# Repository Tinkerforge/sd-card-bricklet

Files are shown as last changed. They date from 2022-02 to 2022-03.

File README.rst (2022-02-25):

SD Card Bricklet
================

**This Bricklet is currently in development.**

This repository contains the firmware source code and the hardware design
files. The documentation generator configs can be found at
https://github.com/Tinkerforge/generators

Repository Content
------------------

software/:
 * examples/: Examples for all supported languages
 * build/: Compiled files
 * src/: Source code of firmware
 * Makefile: Makefile to build project

hardware/:
 * Contains KiCad project files and additionally schematics as PDF

datasheets/:
 * Contains datasheets for sensors and complex ICs that are used

Hardware
--------

The hardware is designed with the open source EDA Suite KiCad
(http://www.kicad.org). Before you are able to open the files,
you have to install the Tinkerforge kicad-libraries
(https://github.com/Tinkerforge/kicad-libraries). You can either clone
them directly in hardware/ or clone them in a separate folder and
symlink them into hardware/
(ln -s kicad_path/kicad-libraries project_path/hardware). After that you
can open the .pro file in hardware/ with KiCad and from there view and
modify the schematics and the PCB layout.

Software
--------

If you want to do your own Brick/Bricklet firmware development we highly
recommend that you use our build environment setup script and read the
tutorial (https://www.tinkerforge.com/en/doc/Tutorials/Tutorial_Build_Environment/Tutorial.html).

To compile the C code we recommend you to install the newest GNU Arm Embedded
Toolchain (https://launchpad.net/gcc-arm-embedded/+download).
You also need to install bricklib2 (https://github.com/Tinkerforge/bricklib2).

You can either clone it directly in software/src/ or clone it in a
separate folder and symlink it into software/src/
(ln -s bricklib_path/bricklib2 project_path/software/src/). Finally make sure to
have CMake installed (http://www.cmake.org/cmake/resources/software.html).

After that you can build the firmware by invoking make in software/.
The firmware (.zbin) can then be found in software/build/ and uploaded
with brickv (click button "Flashing" on start screen).

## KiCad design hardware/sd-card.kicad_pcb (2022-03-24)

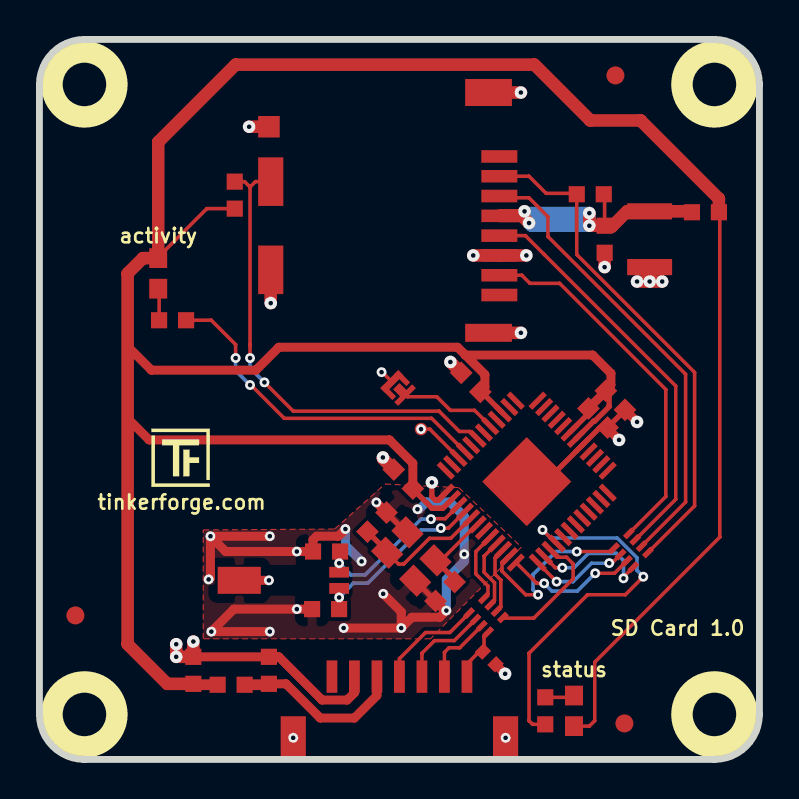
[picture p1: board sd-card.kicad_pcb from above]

Board: 2 copper layers, 40.0 x 40.0 mm, 39 parts (0 on the bottom side), 31 nets.

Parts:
C1: 220pF; C0402F
C2, C5: 1uF; C0603F
C3, C4: 10pF; C0603F
C6, C7, C8, C11: 100nF; C0603F
C9: 220nF; C0603F
C10: 100uF; C1210
C12, C13: 15pF; C0603F
D1: blue; D0603E
D2: red; D0603E
FB1: FILTER; R0603F
Fiducial_Mark: VAL**; Fiducial_Mark
Fiducial_Mark#2, Fiducial_Mark#3: VAL**; Fiducial_Mark
J1: DM3CS; SD-Card-DM3CS
L1: FB; R0603F
P1: CON-SENSOR2
P2: BOOT; SolderJumper
P3: Debug; DEBUG_PAD
R1, R2: 10k; R0603F
R3, R4: 1k; R0603F
RP1, RP2: 82; 4X0402
U1: XMC1404; QFN48-EP2
U2, U3, U4, U5: DRILL; DRILL_NP
VAL: WEEE_7mm
VAL#2: CE_5mm
X1: 16MHz; CRYSTAL_3225
X2: 32.768kHz; AB26TRQ

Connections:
GND: C1.2, C2.1, C3.2, C4.2, C5.1, C6.2, C7.2, C8.2, C9.2, C10.2, C11.2, C12.1, C13.1, J1.6, J1.S, P1.2, P1.EP, P2.1, U1.17, U1.37, U1.EP, X1.3, X2.3
unnamed: C1.1, P1.7, RP1.4
unnamed: C2.2, FB1.1, P1.3
unnamed: C3.1, U1.41, X1.2
unnamed: C4.1, U1.42, X1.1
unnamed: C10.1, C11.1, J1.4, L1.1, R2.2
unnamed: D1.2, R4.1
unnamed: D2.2, R3.1
unnamed: J1.2, R2.1, RP2.1
unnamed: J1.3, RP2.2
unnamed: J1.5, RP2.3
unnamed: J1.7, RP2.4
unnamed: P1.4, RP1.1
unnamed: P1.5, RP1.2
unnamed: P1.6, RP1.3
unnamed: P2.2, U1.29
unnamed: P3.1, U1.34
unnamed: R3.2, U1.33
unnamed: R4.2, U1.4
RTC-XTAL1: C13.2, U1.39, X2.2
RTC-XTAL2: C12.2, U1.40, X2.1
S-CLK: RP1.7, U1.45
S-CS: RP1.8, U1.44
S-MISO: RP1.5, U1.3
S-MOSI: RP1.6, U1.46
SD-CDS: J1.CDS, R1.1, U1.31
SD-CLK: RP2.6, U1.1
SD-CS: RP2.8, U1.2
SD-MISO: RP2.5, U1.47
SD-MOSI: RP2.7, U1.48
VCC: C5.2, C6.1, C7.1, C8.1, C9.1, D1.1, D2.1, FB1.2, L1.2, R1.2, U1.18, U1.19, U1.27, U1.38

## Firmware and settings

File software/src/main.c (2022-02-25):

/* sd-card-bricklet
 * Copyright (C) 2022 Olaf Lüke <olaf@tinkerforge.com>
 *
 * main.c: Initialization for SD Card Bricklet
 *
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
 * You should have received a copy of the GNU Lesser General Public
 * License along with this library; if not, write to the
 * Free Software Foundation, Inc., 59 Temple Place - Suite 330,
 * Boston, MA 02111-1307, USA.
 */

#include <stdio.h>
#include <stdbool.h>

#include "configs/config.h"

#include "bricklib2/bootloader/bootloader.h"
#include "bricklib2/hal/system_timer/system_timer.h"
#include "bricklib2/logging/logging.h"
#include "communication.h"

int main(void) {
	logging_init();
	logd("Start SD Card Bricklet\n\r");

	communication_init();

	while(true) {
		bootloader_tick();
		communication_tick();
	}
}

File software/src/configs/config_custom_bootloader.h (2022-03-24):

/* sd-card-bricklet
 * Copyright (C) 2022 Olaf Lüke <olaf@tinkerforge.com>
 *
 * config_custom_bootloader.h: Bootloader configurations for
 *                             SD Card Bricklet
 *
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
 * You should have received a copy of the GNU Lesser General Public
 * License along with this library; if not, write to the
 * Free Software Foundation, Inc., 59 Temple Place - Suite 330,
 * Boston, MA 02111-1307, USA.
 */

#ifndef CONFIG_CUSTOM_BOOTLOADER_H
#define CONFIG_CUSTOM_BOOTLOADER_H

#include "xmc_gpio.h"

// --- Basic defines ---
#define BOOTLOADER_DEVICE_IDENTIFIER   2172
#define BOOTLOADER_HW_VERSION_MAJOR    1
#define BOOTLOADER_HW_VERSION_MINOR    0
#define BOOTLOADER_HW_VERSION_REVISION 0

#define BOOTLOADER_STATUS_LED_PIN      P4_5
#define BOOTLOADER_BOOT_PAD_PIN        P4_6

#define BOOTLOADER_FLASH_EEPROM_SIZE   (4*256)
#define BOOTLOADER_FLASH_SIZE          (64*1024 - BOOTLOADER_FLASH_EEPROM_SIZE)

#define BOOTLOADER_FIX_POINTER_END

// --- Oscillator defines ---
#define OSCHP_FREQUENCY 16000000
#define DCLK_CLOCK_SRC  1
#define DCO1_CAL_SRC    1

// --- SPITFP ---
#define SPITFP_USIC_CHANNEL         USIC0_CH1
#define SPITFP_USIC                 XMC_SPI0_CH1

#define SPITFP_SCLK_PIN             P1_3
#define SPITFP_SCLK_INPUT           XMC_USIC_CH_INPUT_DX1
#define SPITFP_SCLK_SOURCE          0b000 // DX1A

#define SPITFP_SELECT_PIN           P1_1
#define SPITFP_SELECT_INPUT         XMC_USIC_CH_INPUT_DX2
#define SPITFP_SELECT_SOURCE        0b100 // DX2E

#define SPITFP_MOSI_PIN             P1_2
#define SPITFP_MOSI_INPUT           XMC_USIC_CH_INPUT_DX0
#define SPITFP_MOSI_SOURCE          0b001 // DX0B

#define SPITFP_MISO_PIN             P1_6
#define SPITFP_MISO_PIN_AF          (XMC_GPIO_MODE_OUTPUT_PUSH_PULL_ALT2 | P1_6_AF_U0C1_DOUT0)

#define SPITFP_RECEIVE_BUFFER_SIZE  1024
#define SPITFP_RECEIVE_BUFFER_MASK  (SPITFP_RECEIVE_BUFFER_SIZE-1) // If size is power of 2

#define SPITFP_SERVICE_REQUEST_RX   0
#define SPITFP_SERVICE_REQUEST_TX   1

#define SPITFP_IRQ_RX               9
#define SPITFP_IRQ_RX_PRIORITY      2
#define SPITFP_IRQ_TX               10
#define SPITFP_IRQ_TX_PRIORITY      3

#define SPITFP_TX_DATA_POINTER      16
#define SPITFP_TX_SIZE              XMC_USIC_CH_FIFO_SIZE_16WORDS
#define SPITFP_TX_LIMIT             8

#define SPITFP_RX_DATA_POINTER      0
#define SPITFP_RX_SIZE              XMC_USIC_CH_FIFO_SIZE_16WORDS
#define SPITFP_RX_LIMIT             0

// --- BOOTLOADER FUNCTIONS ---

// define bootloader functions to put them into the BootloaderFunctions struct
// These functions are in the bootloader code and can be used from the firmware

#define BOOTLOADER_FUNCTION_SPITFP_TICK
#define BOOTLOADER_FUNCTION_SEND_ACK_AND_MESSAGE
#define BOOTLOADER_FUNCTION_SPITFP_IS_SEND_POSSIBLE
#define BOOTLOADER_FUNCTION_AEABI_IDIV
#define BOOTLOADER_FUNCTION_AEABI_UIDIV
#define BOOTLOADER_FUNCTION_AEABI_IDIVMOD
#define BOOTLOADER_FUNCTION_AEABI_UIDIVMOD
#define BOOTLOADER_FUNCTION_GET_UID
#define BOOTLOADER_FUNCTION_READ_EEPROM_PAGE
#define BOOTLOADER_FUNCTION_WRITE_EEPROM_PAGE

#endif

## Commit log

2022-02-25 Add initial auto-generated firmware stub for SD Card Bricklet
    [cmake_config_custom.txt]
2022-03-24 add sd card bricklet 1.0
    [sd-card.kicad_pcb, sd-card.sch]
2022-03-24 drc check
    [sd-card.kicad_pcb]
2022-03-24 Add initial sd card with fatfs support
    sdmmc support is based on code generated by Infineon DAVE IDE.
    The FatFs library is updated to newest version.
    Currently only sd card read/write test code is run.

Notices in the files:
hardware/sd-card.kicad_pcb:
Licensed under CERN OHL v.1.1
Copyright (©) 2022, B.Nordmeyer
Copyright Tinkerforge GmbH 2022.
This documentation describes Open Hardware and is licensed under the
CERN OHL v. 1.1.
